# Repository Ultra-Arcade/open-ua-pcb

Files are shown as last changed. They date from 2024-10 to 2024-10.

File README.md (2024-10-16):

# Open Ultra Arcade PCBs

This repository is a collection of open-source hardware designs made by Ultra Arcade.

# [16WASD MX Southpaw Passthrough](/16WASD%20MX%20Southpaw%20Passthrough)

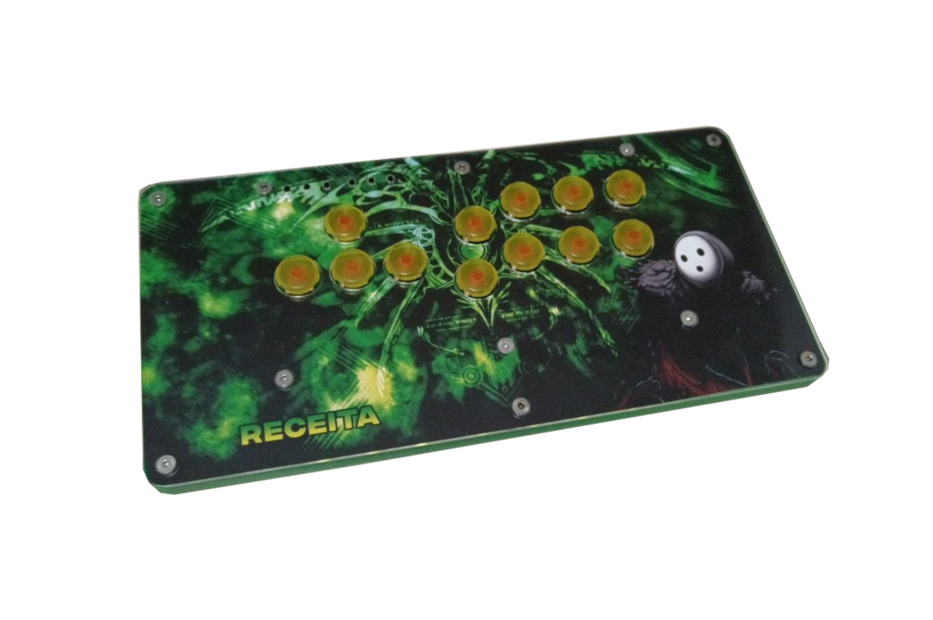
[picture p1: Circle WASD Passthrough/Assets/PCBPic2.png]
16WASD MX Southpaw Passthrough Picture


# [WASD Kailh MX Passthrough](/WASD%20Kailh%20MX%20Passthrough)

WASD Kailh MX Passthrough Picture

# [Circle WASD Passthrough](/Circle%20WASD%20Passthrough)

Circle WASD Passthrough Picture

# [16B Passthrough](/16B%20Passthrough)

16B Passthrough Picture

# Licensing

Check the LICENSE of each design for details on how the design can be used.

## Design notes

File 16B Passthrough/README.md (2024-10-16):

# 16B Passthrough
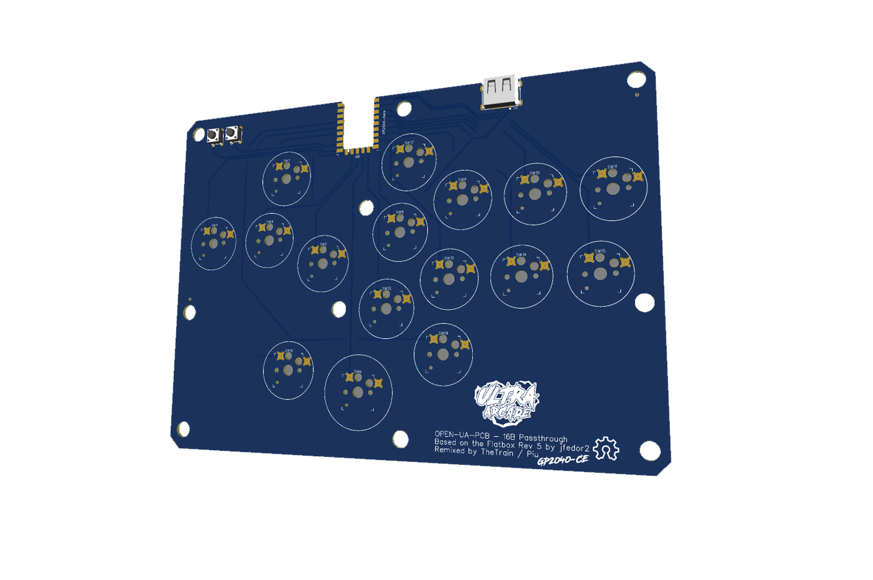
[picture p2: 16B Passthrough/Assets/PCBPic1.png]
16B Passthrough 1


16B Passthrough 2

---

## Attribution

The following text must be included in any distribution of derivatives of this board. All links must also be included.

Based on the Flatbox Rev 5 Passthrough from the GP2040-CE project located at https://github.com/OpenStickCommunity/Hardware/tree/main/Boards/GP2040-CE%20Official%20Controllers/Flatbox%20Rev%205%20Passthrough
Based on the original Flatbox Flatbox Rev 5 project located at https://github.com/jfedor2/flatbox/tree/master/hardware-rev5

Copyright 2024 [Ultra Arcade](https://github.com/Ultra-Arcade)

[Licensed under CC BY 4.0](https://creativecommons.org/licenses/by/4.0/)

Changes from the original design:
  - list any changes you make here

---

## Summary: 

A 16 face button-style Flatbox.

While BOM and CPL files are provided, it is recommended to order and assemble these yourself.

---

## How to order a board

All of the boards so far have been ordered though JLCPCB.  Due to minimum order numbers you would get five of these at a time.  It is not recommended to have these assembed by JLC due to cost.  If you are looking to have them assembled you should check out another project that has an embedded RP2040.

Please note that you will need to source and solder your own Waveshare RP2040-Zero board (or similar), passthrough port, tactile switches and hotswap sockets.

1 - Go to JLCPCB.com<br/>

2 - Click on `Instant Quote`<br/>

3 - Click on `Add Gerber file` and choose the file named `Gerber - 16B Passthrough.zip` from the `Hardware Files` folder<br/>

4 - Choose the following options for the board:<br/>
- Base Material = FR-4<br/>
- Layers = 2<br/>
- Dimensions = (should auto-populate) 210 mm x 120 mm<br/>
- PCB Qty = (however large your run will be, minimum of 5)<br/>
- Product Type = Industrial/Consumer electronics<br/>
- Different Design = 1<br/>
- Delivery Format = Single PCB<br/>
- PCB Thickness = 1.6<br/>
- PCB Color = (up to you)<br/>
- Silkscreen = (defaults to white for all except white boards which is black)<br/>
- Surface Finish = HASL(with lead)<br/>
- Outer Copper Weight = 1oz<br/>
- Via Covering = Tented<br/>
- Board Outline Tolerance = +/- 0.2mm (Regular)<br/>
- Confirm Production file = Yes<br/>
- Remove Order Number = Yes<br/>
- Flying Probe Test = Fully Test<br/>
- Gold Fingers = No<br/>
- Castellated Holes = No<br/>
- No advanced options<br/>

If all looks well here you can click on the `SAVE TO CART` button.

5 - The `Secure Checkout` process will be different based on your location in the world.  We recommend researching your shipping options to choose the one that is right for your application. 

You will need the following parts to assemble the Circle WASD Passthrough:
- 2 x 6x6x7 tactile switches - [LINK](https://www.aliexpress.com/item/1005004159746274.html)
- 1 x Waveshare RP2040 Zero, clone or similar - [LINK](https://www.aliexpress.com/item/1005005910512138.html)
- 1 x Mid-mount USB passthrough port - [LINK](https://www.aliexpress.com/item/1005005686242161.html)
- 16 x Kailh Hotswap Sockets - [LINK](https://www.aliexpress.com/item/1005004916925259.html)
- 16 x Kailh Choc V2 Switches - [LINK](https://www.aliexpress.com/item/1005005066626541.html)
- 16 x Kailh Choc V2 Round Keycaps - [LINK](https://www.aliexpress.com/item/1005004526308262.html)
- 8 x M4 Rivet Nuts - [LINK](https://www.aliexpress.com/item/1005005242016053.html)
- 8 x M4x10 Bolts - [LINK](https://www.aliexpress.com/item/1005005493205421.html)

---

Attribution:

The main PCB was redesigned by Ultra Arcade in EasyEDA.  All source files for this are located in the `Source Files` folder.

The initial Flatbox design was made by Jfedor. A remix was then designed by TheTrain. Our version is a remix from TheTrain's version of the pcb.

---

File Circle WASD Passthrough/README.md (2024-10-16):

# Circle WASD Passthrough
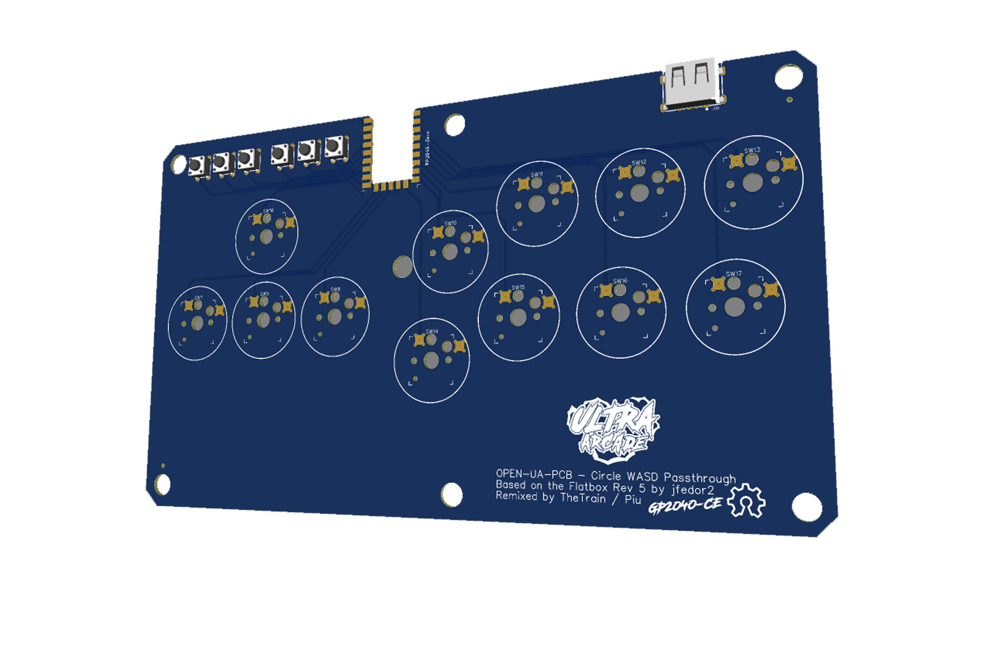
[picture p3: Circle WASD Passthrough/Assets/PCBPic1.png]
Circle WASD Passthrough 1


Circle WASD Passthrough 2

---

## Attribution

The following text must be included in any distribution of derivatives of this board. All links must also be included.

Based on the Flatbox Rev 5 Passthrough from the GP2040-CE project located at https://github.com/OpenStickCommunity/Hardware/tree/main/Boards/GP2040-CE%20Official%20Controllers/Flatbox%20Rev%205%20Passthrough
Based on the original Flatbox Flatbox Rev 5 project located at https://github.com/jfedor2/flatbox/tree/master/hardware-rev5

Copyright 2024 [Ultra Arcade](https://github.com/Ultra-Arcade)

[Licensed under CC BY 4.0](https://creativecommons.org/licenses/by/4.0/)

Changes from the original design:
  - list any changes you make here

---

## Summary: 

An alternate WASD aligned Flatbox.

While BOM and CPL files are provided, it is recommended to order and assemble these yourself.

---

## How to order a board

All of the boards so far have been ordered though JLCPCB.  Due to minimum order numbers you would get five of these at a time.  It is not recommended to have these assembed by JLC due to cost.  If you are looking to have them assembled you should check out another project that has an embedded RP2040.

Please note that you will need to source and solder your own Waveshare RP2040-Zero board (or similar), passthrough port, tactile switches and hotswap sockets.

1 - Go to JLCPCB.com<br/>

2 - Click on `Instant Quote`<br/>

3 - Click on `Add Gerber file` and choose the file named `Gerber - Circle WASD Passthrough.zip` from the `Hardware Files` folder<br/>

4 - Choose the following options for the board:<br/>
- Base Material = FR-4<br/>
- Layers = 2<br/>
- Dimensions = (should auto-populate) 210 mm x 120 mm<br/>
- PCB Qty = (however large your run will be, minimum of 5)<br/>
- Product Type = Industrial/Consumer electronics<br/>
- Different Design = 1<br/>
- Delivery Format = Single PCB<br/>
- PCB Thickness = 1.6<br/>
- PCB Color = (up to you)<br/>
- Silkscreen = (defaults to white for all except white boards which is black)<br/>
- Surface Finish = HASL(with lead)<br/>
- Outer Copper Weight = 1oz<br/>
- Via Covering = Tented<br/>
- Board Outline Tolerance = +/- 0.2mm (Regular)<br/>
- Confirm Production file = Yes<br/>
- Remove Order Number = Yes<br/>
- Flying Probe Test = Fully Test<br/>
- Gold Fingers = No<br/>
- Castellated Holes = No<br/>
- No advanced options<br/>

If all looks well here you can click on the `SAVE TO CART` button.

5 - The `Secure Checkout` process will be different based on your location in the world.  We recommend researching your shipping options to choose the one that is right for your application. 

You will need the following parts to assemble the Circle WASD Passthrough:
- 6 x 6x6x7 tactile switches - [LINK](https://www.aliexpress.com/item/1005004159746274.html)
- 1 x Waveshare RP2040 Zero, clone or similar - [LINK](https://www.aliexpress.com/item/1005005910512138.html)
- 1 x Mid-mount USB passthrough port - [LINK](https://www.aliexpress.com/item/1005005686242161.html)
- 12 x Kailh Hotswap Sockets - [LINK](https://www.aliexpress.com/item/1005004916925259.html)
- 12 x Kailh Choc V2 Switches - [LINK](https://www.aliexpress.com/item/1005005066626541.html)
- 12 x Kailh Choc V2 Round Keycaps - [LINK](https://www.aliexpress.com/item/1005004526308262.html)
- 11 x M4 Rivet Nuts - [LINK](https://www.aliexpress.com/item/1005005242016053.html)
- 11 x M4x10 Bolts - [LINK](https://www.aliexpress.com/item/1005005493205421.html)

---

Attribution:

The main PCB was redesigned by Ultra Arcade in EasyEDA.  All source files for this are located in the `Source Files` folder.

The initial Flatbox design was made by Jfedor. A remix was then designed by TheTrain. Our version is a remix from TheTrain's version of the pcb.

---

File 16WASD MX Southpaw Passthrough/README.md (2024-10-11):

# 16WASD MX Southpaw Passthrough
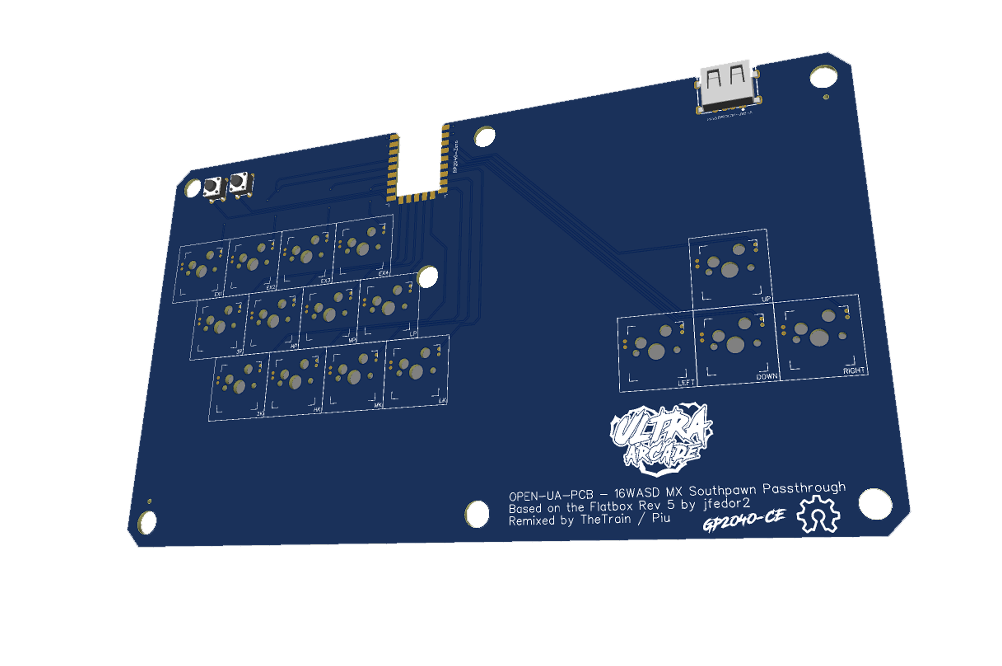
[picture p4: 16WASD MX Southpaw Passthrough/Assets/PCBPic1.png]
16WASD MX Southpaw Passthrough 1


16WASD MX Southpaw Passthrough 2

---

## Attribution

The following text must be included in any distribution of derivatives of this board. All links must also be included.

Based on the Flatbox Rev 5 Passthrough from the GP2040-CE project located at https://github.com/OpenStickCommunity/Hardware/tree/main/Boards/GP2040-CE%20Official%20Controllers/Flatbox%20Rev%205%20Passthrough
Based on the original Flatbox Flatbox Rev 5 project located at https://github.com/jfedor2/flatbox/tree/master/hardware-rev5

Copyright 2024 [Ultra Arcade](https://github.com/Ultra-Arcade)

[Licensed under CC BY 4.0](https://creativecommons.org/licenses/by/4.0/)

Changes from the original design:
  - list any changes you make here

---

## Summary: 

A WASD Southpaw and 16 button MX controller with a passthrough port.

While BOM and CPL files are provided, it is recommended to order and assemble these yourself.

---

## How to order a board

All of the boards so far have been ordered though JLCPCB.  Due to minimum order numbers you would get five of these at a time.  It is not recommended to have these assembed by JLC due to cost.  If you are looking to have them assembled you should check out another project that has an embedded RP2040.

Please note that you will need to source and solder your own Waveshare RP2040-Zero board (or similar), passthrough port, tactile switches and hotswap sockets.

1 - Go to JLCPCB.com<br/>

2 - Click on `Instant Quote`<br/>

3 - Click on `Add Gerber file` and choose the file named `Gerber - 16WASD MX Southpaw Passthrough.zip` from the `Hardware Files` folder<br/>

4 - Choose the following options for the board:<br/>
- Base Material = FR-4<br/>
- Layers = 2<br/>
- Dimensions = (should auto-populate) 210 mm x 120 mm<br/>
- PCB Qty = (however large your run will be, minimum of 5)<br/>
- Product Type = Industrial/Consumer electronics<br/>
- Different Design = 1<br/>
- Delivery Format = Single PCB<br/>
- PCB Thickness = 1.6<br/>
- PCB Color = (up to you)<br/>
- Silkscreen = (defaults to white for all except white boards which is black)<br/>
- Surface Finish = HASL(with lead)<br/>
- Outer Copper Weight = 1oz<br/>
- Via Covering = Tented<br/>
- Board Outline Tolerance = +/- 0.2mm (Regular)<br/>
- Confirm Production file = Yes<br/>
- Remove Order Number = Yes<br/>
- Flying Probe Test = Fully Test<br/>
- Gold Fingers = No<br/>
- Castellated Holes = No<br/>
- No advanced options<br/>

If all looks well here you can click on the `SAVE TO CART` button.

5 - The `Secure Checkout` process will be different based on your location in the world.  We recommend researching your shipping options to choose the one that is right for your application. 

You will need the following parts to assemble the 16WASD MX Southpaw Passthrough:
- 2 x 6x6x7 tactile switches - [LINK](https://www.aliexpress.com/item/1005004159746274.html)
- 1 x Waveshare RP2040 Zero, clone or similar - [LINK](https://www.aliexpress.com/item/1005005910512138.html)
- 1 x Mid-mount USB passthrough port - [LINK](https://www.aliexpress.com/item/1005005686242161.html)
- 16 x CherryMX Hotswap Sockets - [LINK](https://www.aliexpress.com/item/1005006108246232.html)
- 16 x Cherry MX Switches (5 Pins Preferred) - [LINK](https://www.aliexpress.com/item/1005006452799449.html)
- 11 x M4 Rivet Nuts - [LINK](https://www.aliexpress.com/item/1005005242016053.html)
- 11 x M4x10 Bolts - [LINK](https://www.aliexpress.com/item/1005005493205421.html)

---

Attribution:

The main PCB was redesigned by Ultra Arcade in EasyEDA.  All source files for this are located in the `Source Files` folder.

The initial Flatbox design was made by Jfedor. A remix was then designed by TheTrain. Our version is a remix from TheTrain's version of the pcb.

---

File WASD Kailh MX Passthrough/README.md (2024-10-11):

# WASD Kailh MX Passthrough
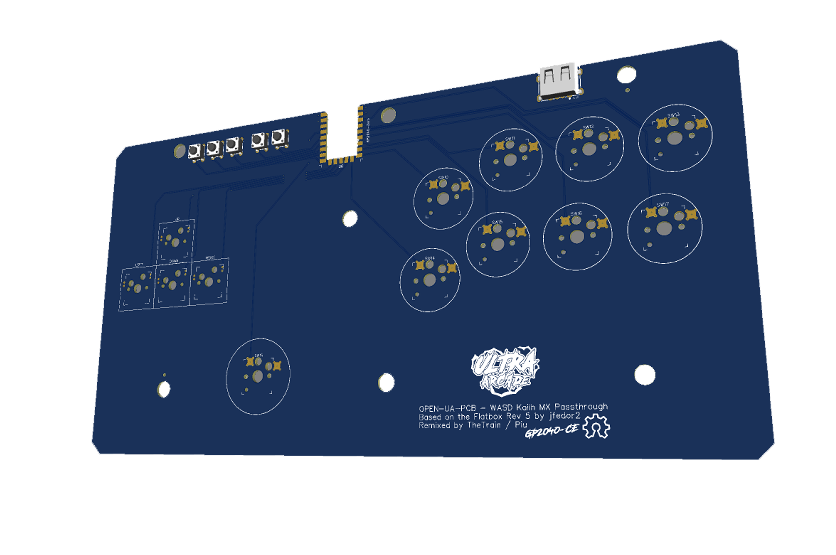
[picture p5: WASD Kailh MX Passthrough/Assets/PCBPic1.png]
WASD Kailh MX Passthrough 1


WASD Kailh MX Passthrough 2

---

## Attribution

The following text must be included in any distribution of derivatives of this board. All links must also be included.

Based on the Flatbox Rev 5 Passthrough from the GP2040-CE project located at https://github.com/OpenStickCommunity/Hardware/tree/main/Boards/GP2040-CE%20Official%20Controllers/Flatbox%20Rev%205%20Passthrough
Based on the original Flatbox Flatbox Rev 5 project located at https://github.com/jfedor2/flatbox/tree/master/hardware-rev5

Copyright 2024 [Ultra Arcade](https://github.com/Ultra-Arcade)

[Licensed under CC BY 4.0](https://creativecommons.org/licenses/by/4.0/)

Changes from the original design:
  - list any changes you make here

---

## Summary: 

An MX and Kailh mix variant with more space between movement and attack buttons. WASD movement with MX hotswap MX keys, attack buttons with Kailh hotswap keys.

While BOM and CPL files are provided, it is recommended to order and assemble these yourself.

---

## How to order a board

All of the boards so far have been ordered though JLCPCB.  Due to minimum order numbers you would get five of these at a time.  It is not recommended to have these assembed by JLC due to cost.  If you are looking to have them assembled you should check out another project that has an embedded RP2040.

Please note that you will need to source and solder your own Waveshare RP2040-Zero board (or similar), passthrough port, tactile switches and hotswap sockets.

1 - Go to JLCPCB.com<br/>

2 - Click on `Instant Quote`<br/>

3 - Click on `Add Gerber file` and choose the file named `Gerber - WASD Kailh MX Passthrough.zip` from the `Hardware Files` folder<br/>

4 - Choose the following options for the board:<br/>
- Base Material = FR-4<br/>
- Layers = 2<br/>
- Dimensions = (should auto-populate) 210 mm x 120 mm<br/>
- PCB Qty = (however large your run will be, minimum of 5)<br/>
- Product Type = Industrial/Consumer electronics<br/>
- Different Design = 1<br/>
- Delivery Format = Single PCB<br/>
- PCB Thickness = 1.6<br/>
- PCB Color = (up to you)<br/>
- Silkscreen = (defaults to white for all except white boards which is black)<br/>
- Surface Finish = HASL(with lead)<br/>
- Outer Copper Weight = 1oz<br/>
- Via Covering = Tented<br/>
- Board Outline Tolerance = +/- 0.2mm (Regular)<br/>
- Confirm Production file = Yes<br/>
- Remove Order Number = Yes<br/>
- Flying Probe Test = Fully Test<br/>
- Gold Fingers = No<br/>
- Castellated Holes = No<br/>
- No advanced options<br/>

If all looks well here you can click on the `SAVE TO CART` button.

5 - The `Secure Checkout` process will be different based on your location in the world.  We recommend researching your shipping options to choose the one that is right for your application. 

You will need the following parts to assemble the WASD Kailh MX Passthrough:
- 5 x 6x6x7 tactile switches - [LINK](https://www.aliexpress.com/item/1005004159746274.html)
- 1 x Waveshare RP2040 Zero, clone or similar - [LINK](https://www.aliexpress.com/item/1005005910512138.html)
- 1 x Mid-mount USB passthrough port - [LINK](https://www.aliexpress.com/item/1005005686242161.html)
- 4 x CherryMX Hotswap Sockets - [LINK](https://www.aliexpress.com/item/1005006108246232.html)
- 4 x Cherry MX Switches (5 Pins Preferred) - [LINK](https://www.aliexpress.com/item/1005006452799449.html)
- 4 x Cherry MX Keycaps - [LINK](https://www.aliexpress.com/item/1005006107037094.html)
- 9 x Kailh Hotswap Sockets - [LINK](https://www.aliexpress.com/item/1005004916925259.html)
- 9 x Kailh Choc V2 Switches - [LINK](https://www.aliexpress.com/item/1005005066626541.html)
- 9 x Kailh Choc V2 Round Keycaps - [LINK](https://www.aliexpress.com/item/1005004526308262.html)
- 11 x M4 Rivet Nuts - [LINK](https://www.aliexpress.com/item/1005005242016053.html)
- 11 x M4x10 Bolts - [LINK](https://www.aliexpress.com/item/1005005493205421.html)

---

Attribution:

The main PCB was redesigned by Ultra Arcade in EasyEDA.  All source files for this are located in the `Source Files` folder.

The initial Flatbox design was made by Jfedor. A remix was then designed by TheTrain. Our version is a remix from TheTrain's version of the pcb.

---

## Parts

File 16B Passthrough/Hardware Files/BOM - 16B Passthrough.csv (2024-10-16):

ID | Name | Designator | Footprint | Quantity | Manufacturer Part | Manufacturer | Supplier | Supplier Part | Price
1 | USB-A-TH_905-761A2022D10202 | U36 | USB-A-TH_905-761A2022D10202 | 1 | 905-761A2022D10202 | 精拓金 | LCSC | C2763020 | 0.078
2 | SW-TH_4P-L6.0-W6.0-P4.50-LS6.5 | U6,U31 | SW-TH_4P-L6.0-W6.0-P4.50-LS6.5 | 2 | KH-6X6X9H-TJ | kinghelm(金航标) | LCSC | C2837519 | 0.014

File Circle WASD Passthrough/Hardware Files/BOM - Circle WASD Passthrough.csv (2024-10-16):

ID | Name | Designator | Footprint | Quantity | Manufacturer Part | Manufacturer | Supplier | Supplier Part | Price
1 | USB-A-TH_905-761A2022D10202 | U36 | USB-A-TH_905-761A2022D10202 | 1 | 905-761A2022D10202 | 精拓金 | LCSC | C2763020 | 0.078
2 | SW-TH_4P-L6.0-W6.0-P4.50-LS6.5 | U6,U31,U32,U33,U34,U35 | SW-TH_4P-L6.0-W6.0-P4.50-LS6.5 | 6 | KH-6X6X9H-TJ | kinghelm(金航标) | LCSC | C2837519 | 0.014

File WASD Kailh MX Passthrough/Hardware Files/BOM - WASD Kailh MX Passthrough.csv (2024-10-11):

ID | Name | Designator | Footprint | Quantity | Manufacturer Part | Manufacturer | Supplier | Supplier Part | Price
1 | CHERRY-MX-HOTSWAP | LEFT,DOWN,RIGHT,UP | CHERRY-MX-HOTSWAP | 4
2 | USB-A-TH_905-761A2022D10202 | U36 | USB-A-TH_905-761A2022D10202 | 1 | 905-761A2022D10202 | 精拓金 | LCSC | C2763020 | 0.078
3 | SW-TH_4P-L6.0-W6.0-P4.50-LS6.5 | U6,U31,U32,U33,U34 | SW-TH_4P-L6.0-W6.0-P4.50-LS6.5 | 5 | KH-6X6X9H-TJ | kinghelm(金航标) | LCSC | C2837519 | 0.014

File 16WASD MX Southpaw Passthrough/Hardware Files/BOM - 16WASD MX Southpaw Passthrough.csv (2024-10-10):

ID | Name | Designator | Footprint | Quantity | Manufacturer Part | Manufacturer | Supplier | Supplier Part | Price
1 | CHERRY-MX-HOTSWAP | UP,LEFT,DOWN,RIGHT,EX1,EX2,EX3,EX4,3P,HP,MP,LP,3K,HK,MK,LK | CHERRY-MX-HOTSWAP | 16
2 | USB-A-TH_905-761A2022D10202 | U36 | USB-A-TH_905-761A2022D10202 | 1 | 905-761A2022D10202 | 精拓金 | LCSC | C2763020 | 0.078
3 | SW-TH_4P-L6.0-W6.0-P4.50-LS6.5 | U6,U31 | SW-TH_4P-L6.0-W6.0-P4.50-LS6.5 | 2 | KH-6X6X9H-TJ | kinghelm(金航标) | LCSC | C2837519 | 0.014

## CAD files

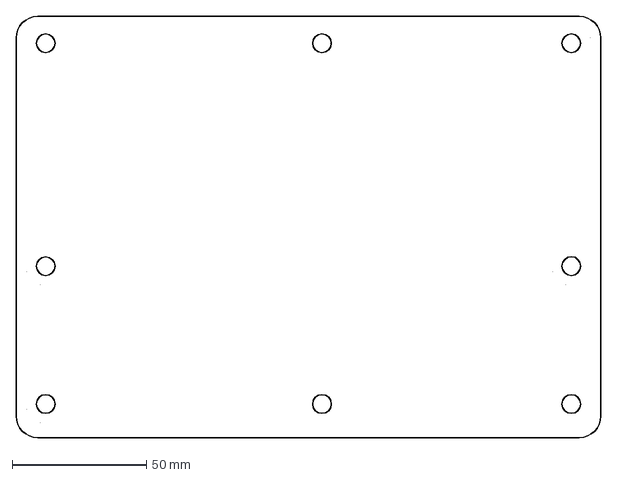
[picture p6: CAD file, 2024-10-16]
16B Passthrough/CNC Files/Layer1_3mm.dxf
218.0 x 157.0 mm

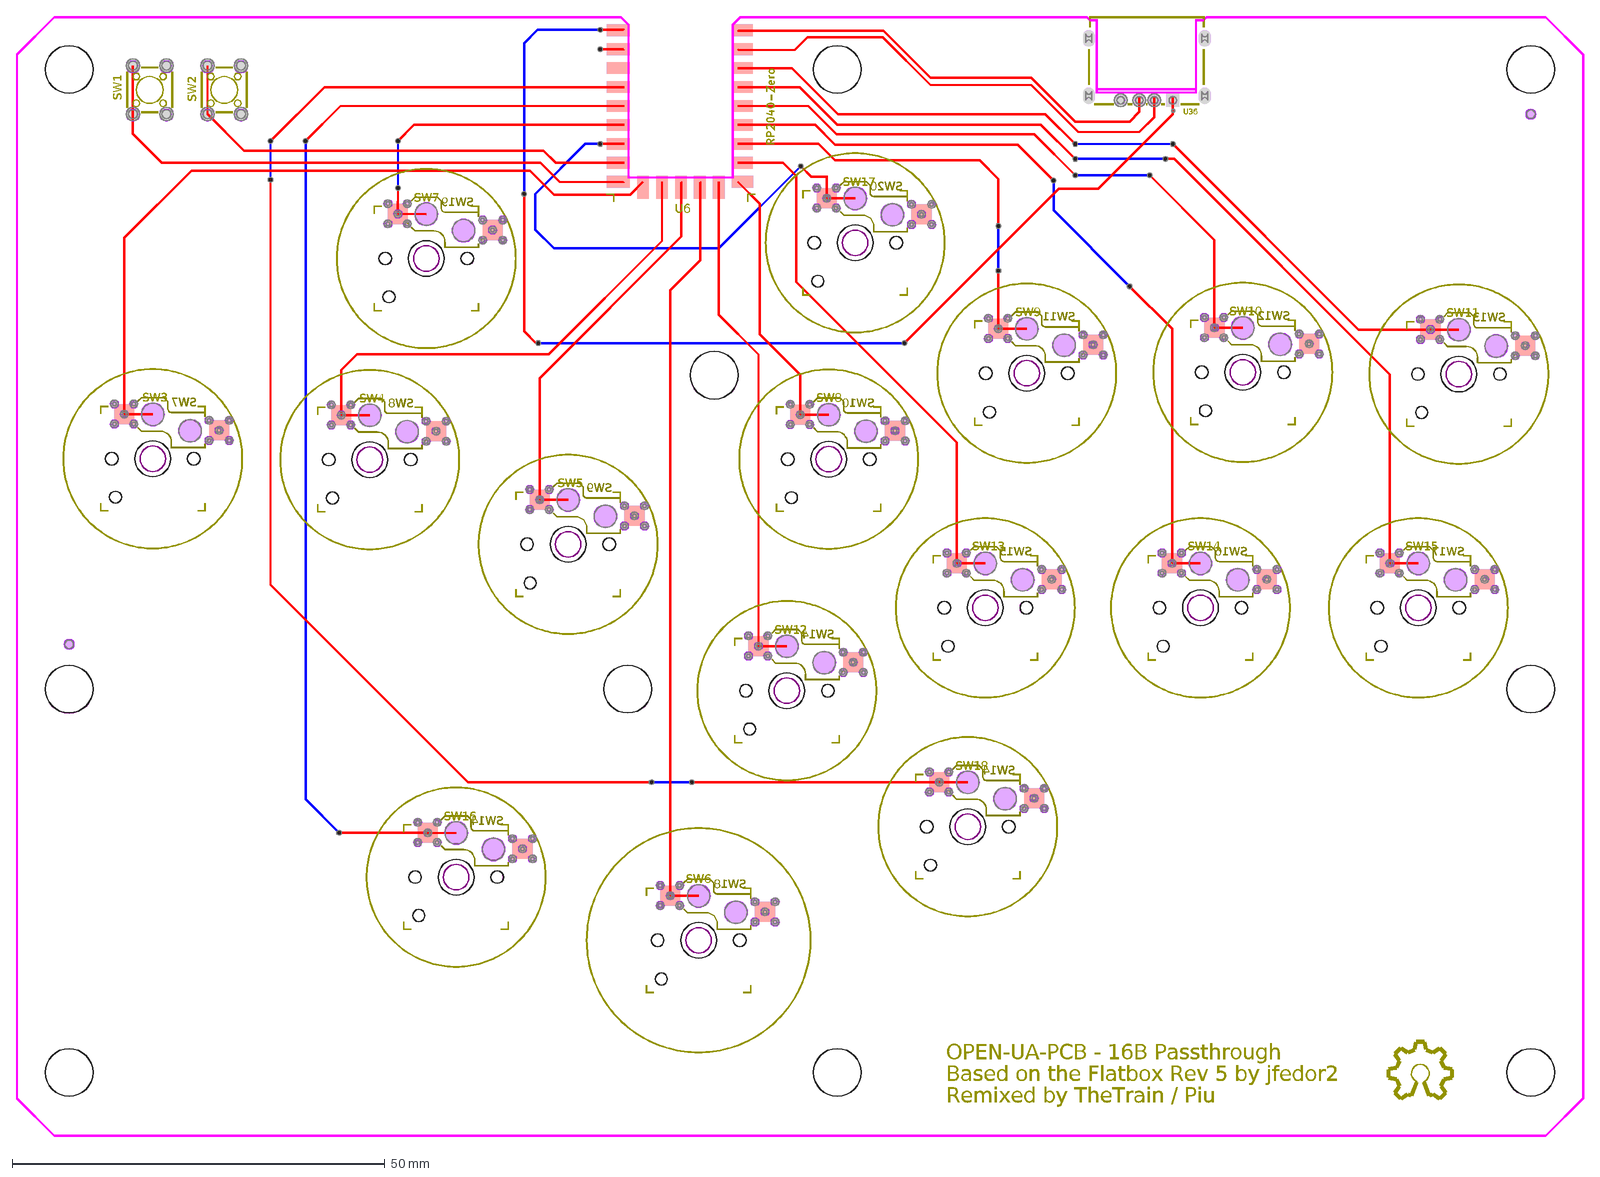
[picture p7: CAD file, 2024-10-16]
16B Passthrough/Source Files/DXF - 16B Passthrough.dxf
SW7
SW8
SW9
SW10
SW11
SW12
SW13
SW17
SW16
SW15
SW14
SW18
SW19
SW20
SW3
SW4
SW5
SW6
U6
SW1
SW2
Remixed by TheTrain / Piu
Based on the Flatbox Rev 5 by jfedor2
OPEN-UA-PCB - 16B Passthrough
U36

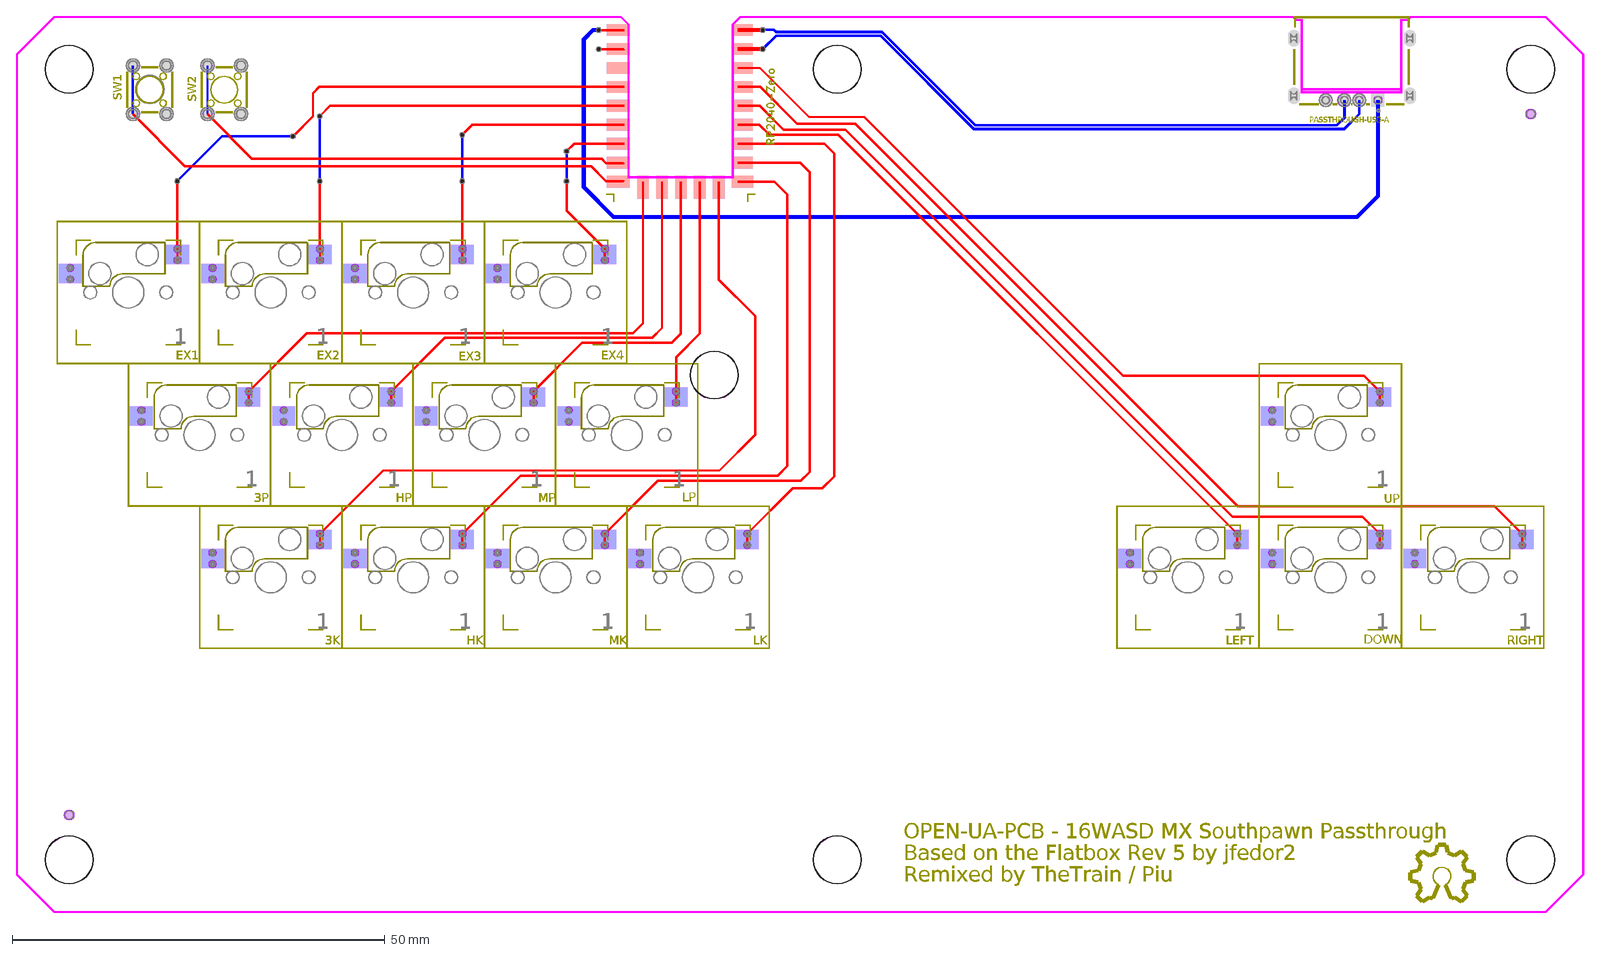
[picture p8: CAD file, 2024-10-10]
16WASD MX Southpaw Passthrough/Source Files/DXF - 16WASD MX Southpaw Passthrough.dxf
OPEN-UA-PCB - 16WASD MX Southpawn Passthrough
Based on the Flatbox Rev 5 by jfedor2
SW1
SW2
Remixed by TheTrain / Piu
UP
1
LEFT
DOWN
RIGHT
EX1
EX2
EX3
EX4
3P
HP
MP
LP
3K
HK
MK
LK
PASSTHROUGH-USB-A

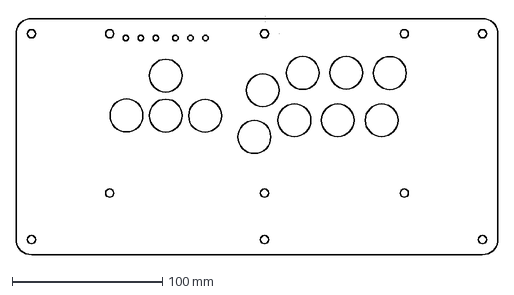
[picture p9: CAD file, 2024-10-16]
Circle WASD Passthrough/CNC Files/Layer6_3mm.dxf
320.0 x 158.4 mm

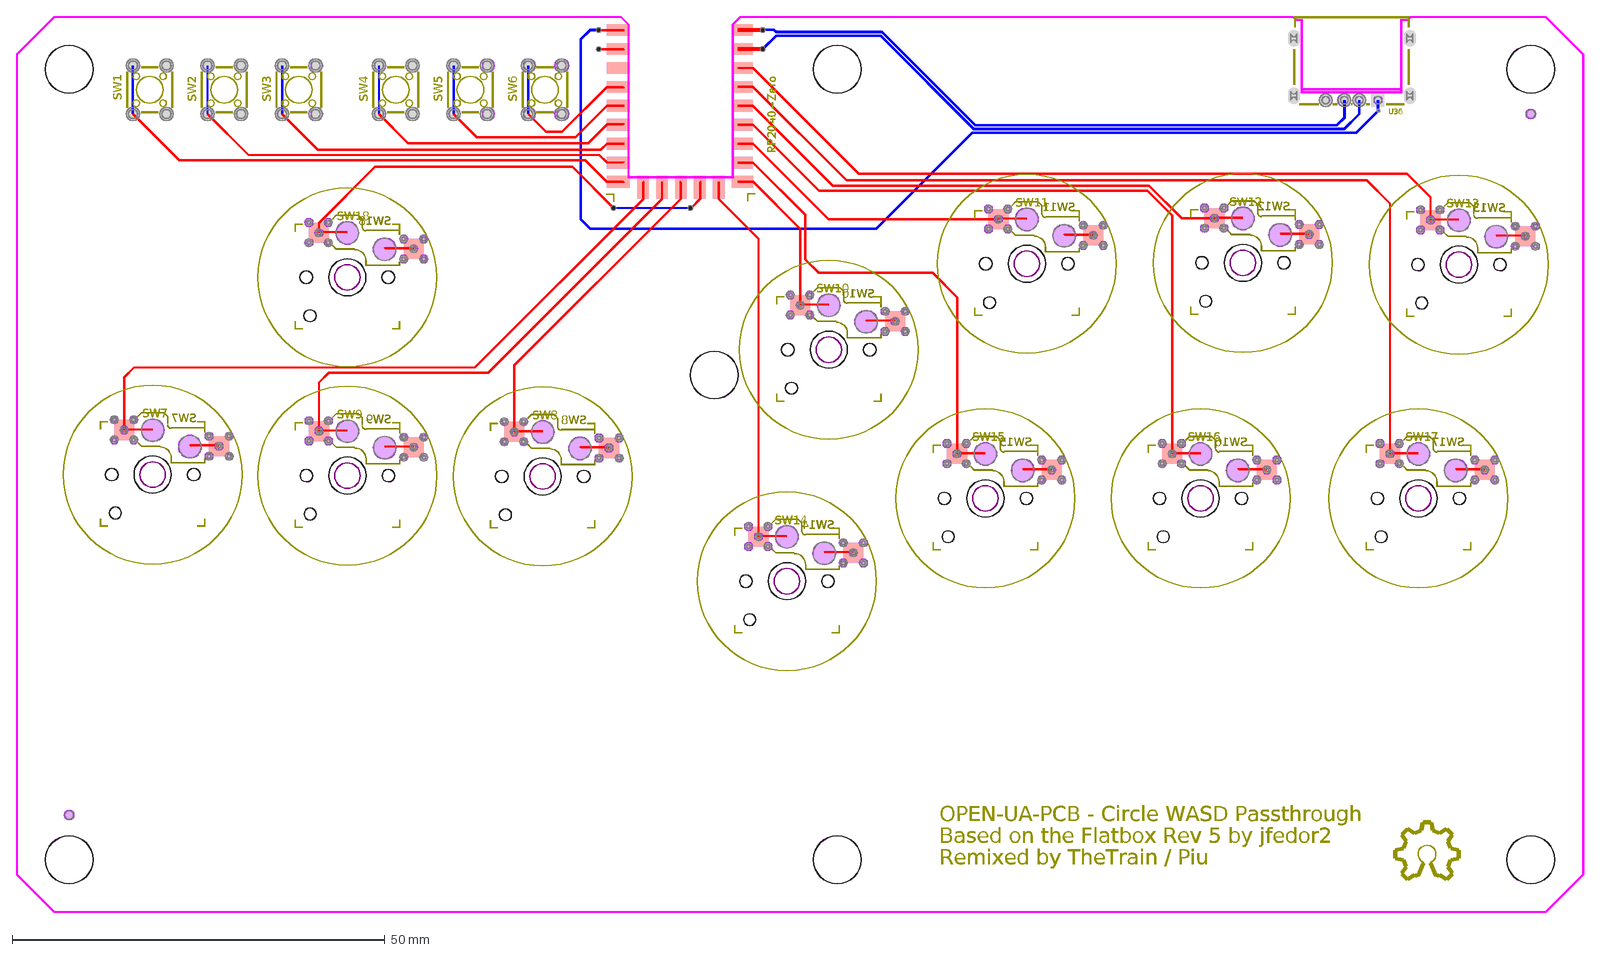
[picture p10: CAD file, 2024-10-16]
Circle WASD Passthrough/Source Files/DXF - Circle WASD Passthrough.dxf
SW7
SW9
SW10
SW11
SW12
SW13
SW17
SW16
SW15
SW14
SW8
SW18
OPEN-UA-PCB - Circle WASD Passthrough
Based on the Flatbox Rev 5 by jfedor2
SW1
SW2
SW3
SW4
SW5
SW6
Remixed by TheTrain / Piu
U36

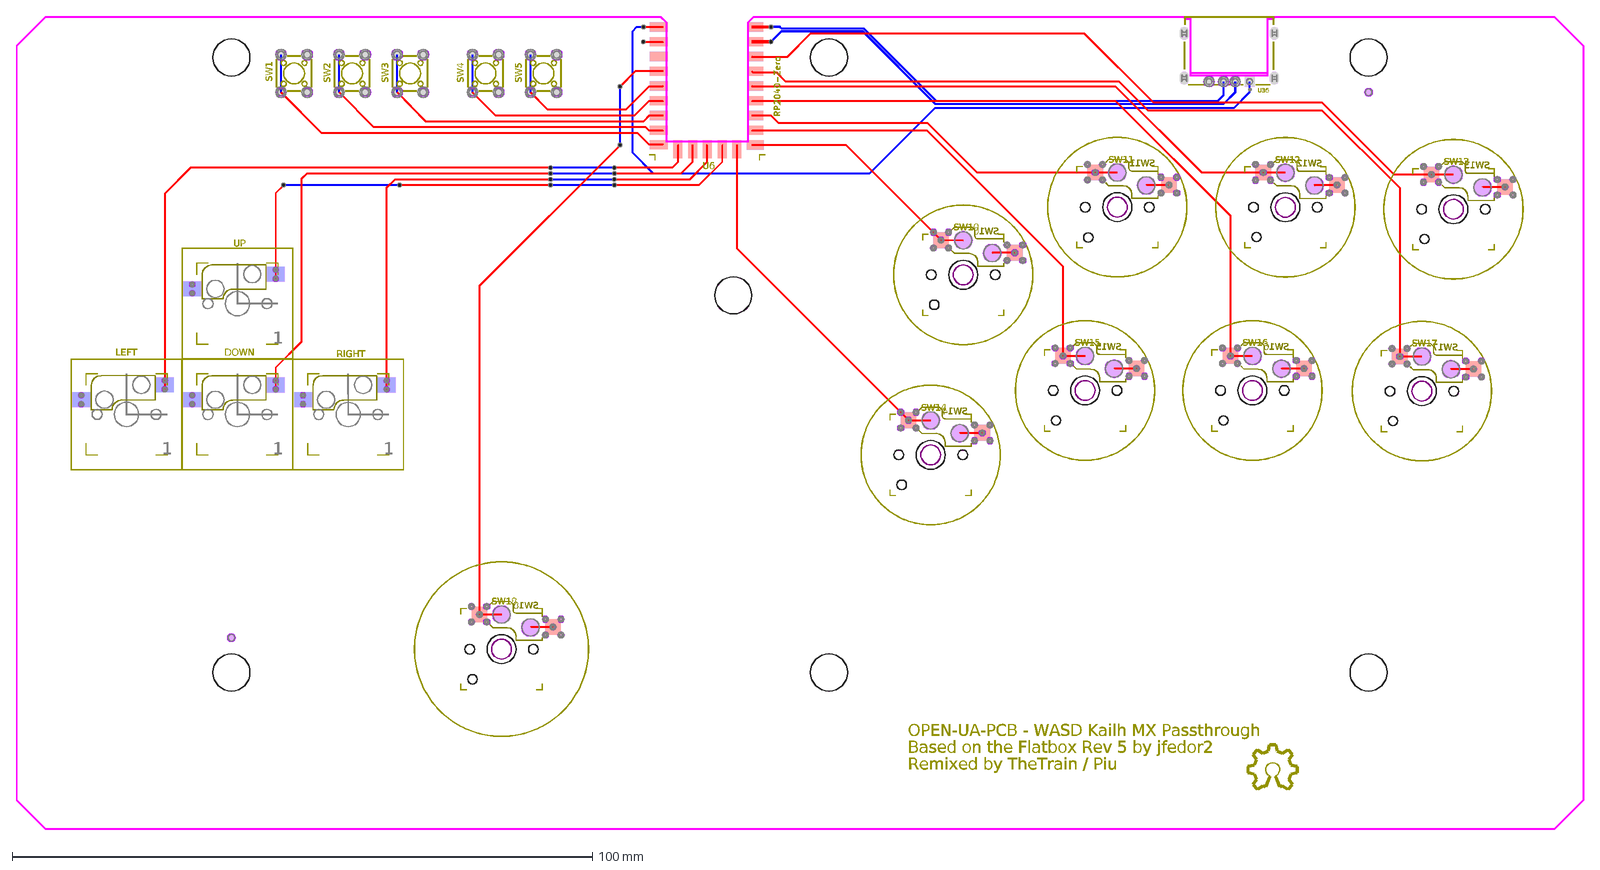
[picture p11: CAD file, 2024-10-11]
WASD Kailh MX Passthrough/Source Files/DXF - WASD Kailh MX Passthrough.dxf
SW17
SW13
SW12
SW16
SW11
SW15
SW10
SW18
SW14
OPEN-UA-PCB - WASD Kailh MX Passthrough
Based on the Flatbox Rev 5 by jfedor2
U6
SW1
SW2
SW3
SW4
SW5
Remixed by TheTrain / Piu
LEFT
1
DOWN
RIGHT
UP
U36

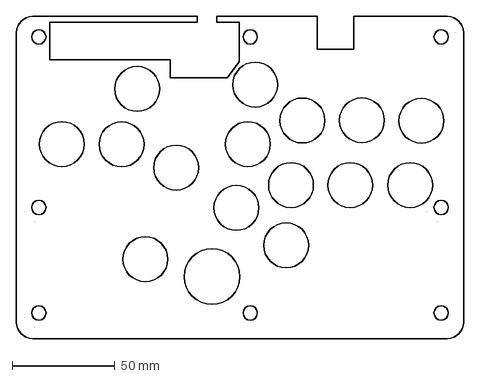
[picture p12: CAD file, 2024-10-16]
16B Passthrough/CNC Files/Layer4_3mm.dxf
218.0 x 157.0 mm

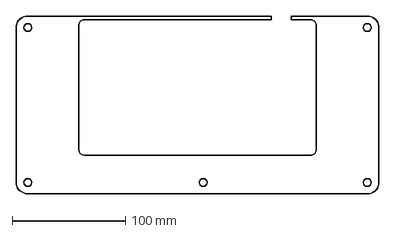
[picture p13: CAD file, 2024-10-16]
Circle WASD Passthrough/CNC Files/Layer3_3mm.dxf
320.0 x 156.9 mm

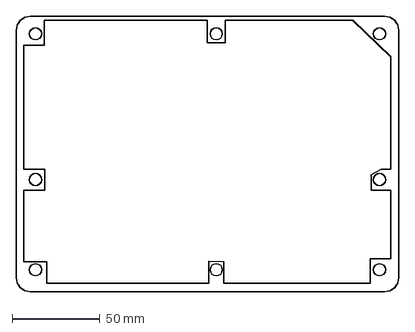
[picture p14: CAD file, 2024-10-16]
16B Passthrough/CNC Files/Layer2_3mm.dxf
218.0 x 157.0 mm

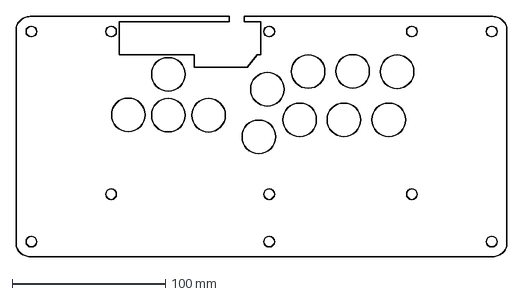
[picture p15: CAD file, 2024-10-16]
Circle WASD Passthrough/CNC Files/Layer4_3mm.dxf
319.9 x 156.9 mm

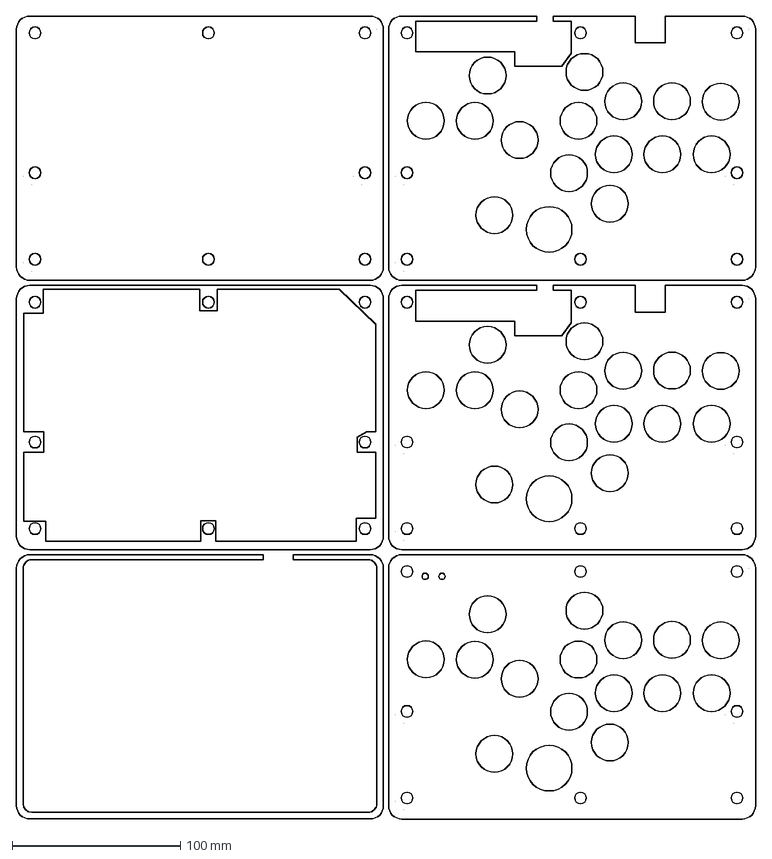
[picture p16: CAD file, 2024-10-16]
16B Passthrough/CNC Files/CombinedLayers_3mm.dxf
439.0 x 477.0 mm

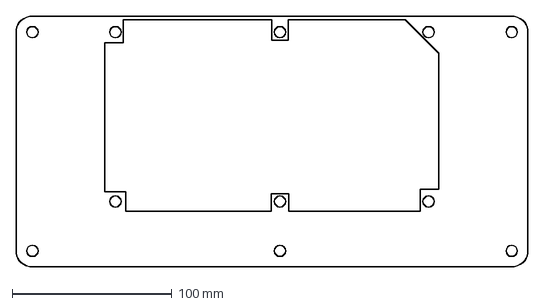
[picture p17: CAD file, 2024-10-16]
Circle WASD Passthrough/CNC Files/Layer2_3mm.dxf
320.0 x 156.9 mm

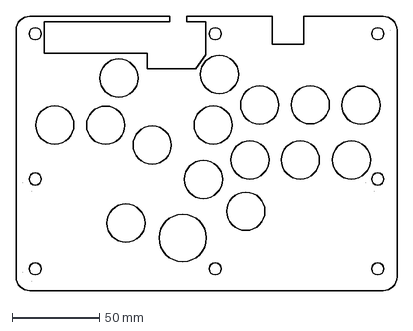
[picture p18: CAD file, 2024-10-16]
16B Passthrough/CNC Files/Layer5_3mm.dxf
218.0 x 157.0 mm

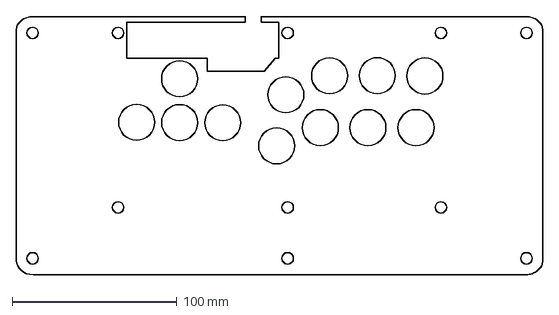
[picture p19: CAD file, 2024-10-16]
Circle WASD Passthrough/CNC Files/Layer5_3mm.dxf
319.9 x 156.9 mm

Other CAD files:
16B Passthrough/CNC Files/Layer6_3mm.dxf
Circle WASD Passthrough/CNC Files/CombinedLayers_3mm.dxf
16B Passthrough/CNC Files/Layer3_3mm.dxf
Circle WASD Passthrough/CNC Files/Layer1_3mm.dxf
16WASD MX Southpaw Passthrough/CNC Files/CombinedLayers_3mm.dxf
16WASD MX Southpaw Passthrough/CNC Files/Layer1_3mm.dxf
16WASD MX Southpaw Passthrough/CNC Files/Layer2_3mm.dxf
16WASD MX Southpaw Passthrough/CNC Files/Layer3_3mm.dxf
16WASD MX Southpaw Passthrough/CNC Files/Layer4_3mm.dxf
16WASD MX Southpaw Passthrough/CNC Files/Layer5_3mm.dxf
16WASD MX Southpaw Passthrough/CNC Files/Layer6_3mm.dxf
WASD Kailh MX Passthrough/CNC Files/CombinedLayers_3mm.dxf
WASD Kailh MX Passthrough/CNC Files/Layer1_3mm.dxf
WASD Kailh MX Passthrough/CNC Files/Layer2_3mm.dxf
WASD Kailh MX Passthrough/CNC Files/Layer3_3mm.dxf
WASD Kailh MX Passthrough/CNC Files/Layer4_3mm.dxf
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

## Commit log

2024-10-10 Added 16WASD MX Southpawn Passthrough
    [BOM - 16WASD MX Southpawn Passthrough.csv, CombinedLayers_3mm.dxf, DXF - 16WASD MX Southpawn Passthrough.dxf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]
2024-10-10 Fixed typos
    [BOM - 16WASD MX Southpaw Passthrough.csv, DXF - 16WASD MX Southpaw Passthrough.dxf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]
2024-10-10 Renamed directory
    [BOM - 16WASD MX Southpaw Passthrough.csv, CombinedLayers_3mm.dxf, DXF - 16WASD MX Southpaw Passthrough.dxf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]
2024-10-11 Added WASD Kailh MX Passthrough
    [BOM - WASD Kailh MX Passthrough.csv, CombinedLayers_3mm.dxf, DXF - WASD Kailh MX Passthrough.dxf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]
2024-10-16 Added CircleWASD and 16B
    [BOM - 16B Passthrough.csv, BOM - Circle WASD Passthrough.csv, CombinedLayers_3mm.dxf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]
